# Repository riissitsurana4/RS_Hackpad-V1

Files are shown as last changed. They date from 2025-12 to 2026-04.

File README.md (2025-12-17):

  # RS_Hackpad-V1

Hello everyone!
This is my first hardware project, built as part of **Blueprint (Hack Club)**.

It is a custom macropad made using switches, a rotatory encoder, oled display, etc.

---

## Case Design

The case consists of **two 3D-printed parts**

* **Top plate**
* **Base case**

Bottom case design

Top plate design

---

## PCB Design

The PCB was designed in **KiCad** and includes the following features:

* **8 mechanical switches** arranged in a matrix (4 columns × 2 rows)
* **8 SK6812 RGB LEDs** for underglow
* **1 rotary encoder**
* **0.91 inch OLED display**
* **Seeed XIAO RP2040** as the MCU

The LEDs are placed near the edges of the PCB to create an underglow effect through the case.

PCB layout

---
## Final Design
Arranged 3D version of all the parts including the pcb.

Final PCB render

---

## Firmware

I have made the firmware using **KMK**. 

I have only made basic firmware as it is very confusing and i do not have anything to test on.

---

## BOM

Seeed XIAO RP2040 

Through-hole 1N4148 Diodes (x9)

MX-Style switches (x8)

EC11 Rotary encoders (x1)

0.91 inch OLED displays

SK6812 MINI-E LEDs (x8)

M3x16mm screws & M3x5mx4mm heatset inserts

---

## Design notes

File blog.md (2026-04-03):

This was my first hardware project which taught me multiple things.... Used KiCad and Fusion for the first time.

I recievd all the parts for my hackpad, but later found out that i did not upload all the files needed for the pcb.
I had not uploaded the drill filles and hence the pcb was without holes needed.
My case does not has any tolerance and is a little small (2mm) than the pcb...

As the pcb is incorect and the case is a little small, was not able to complete this project.... Will definitely make a V2 of this and fix most of my mistakes.

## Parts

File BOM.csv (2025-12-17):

Part Name | Quantity | LINK
SeeedXIAO RP2040 | 1 | HACKPAD KIT
Through-hole 1N4148 Diodes | 9 | HACKPAD KIT
MX-Style switches | 8 | HACKPAD KIT
EC11 Rotary encoders | 1 | HACKPAD KIT
0.91 inch OLED displays | 1 | HACKPAD KIT
SK6812 MINI-E LEDs | 8 | HACKPAD KIT
M3x16mm screws & M3x5mx4mm heatset inserts | 4 | HACKPAD KIT
PCB | 1 | JLPCB
Soldering Iron | 1

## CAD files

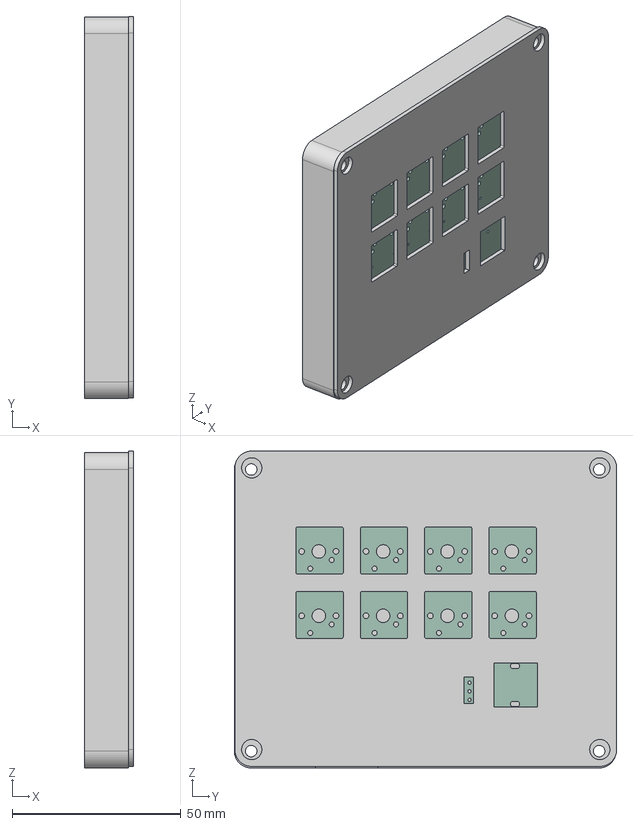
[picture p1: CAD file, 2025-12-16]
CAD/macropad_RS_fullcase.step
14.5 x 113.2 x 93.9 mm

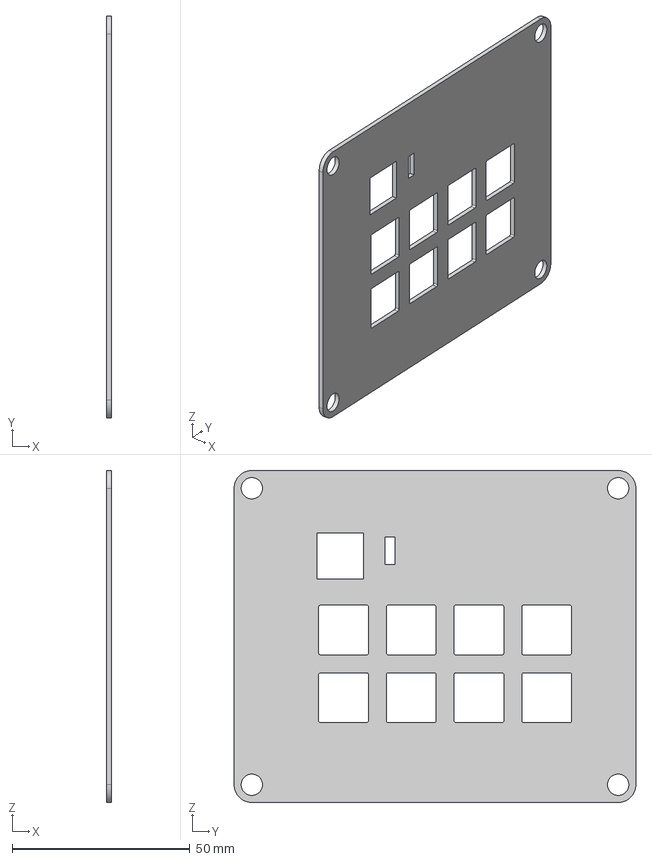
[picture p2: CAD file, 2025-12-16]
CAD/RS_macropad_top.step
1.50 x 113.1 x 93.4 mm

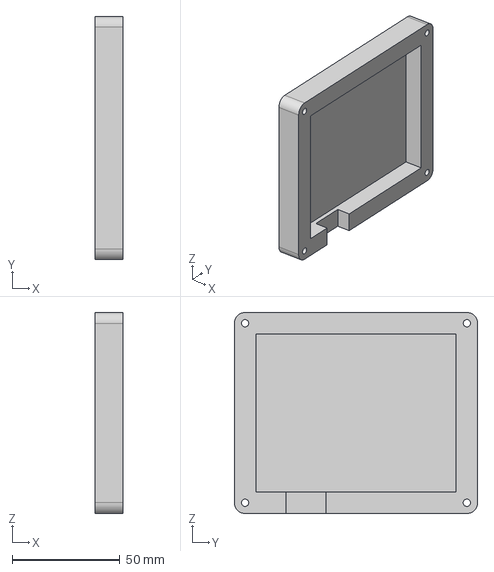
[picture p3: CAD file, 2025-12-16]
CAD/RS Macropad_base.step
13.0 x 113.1 x 93.4 mm

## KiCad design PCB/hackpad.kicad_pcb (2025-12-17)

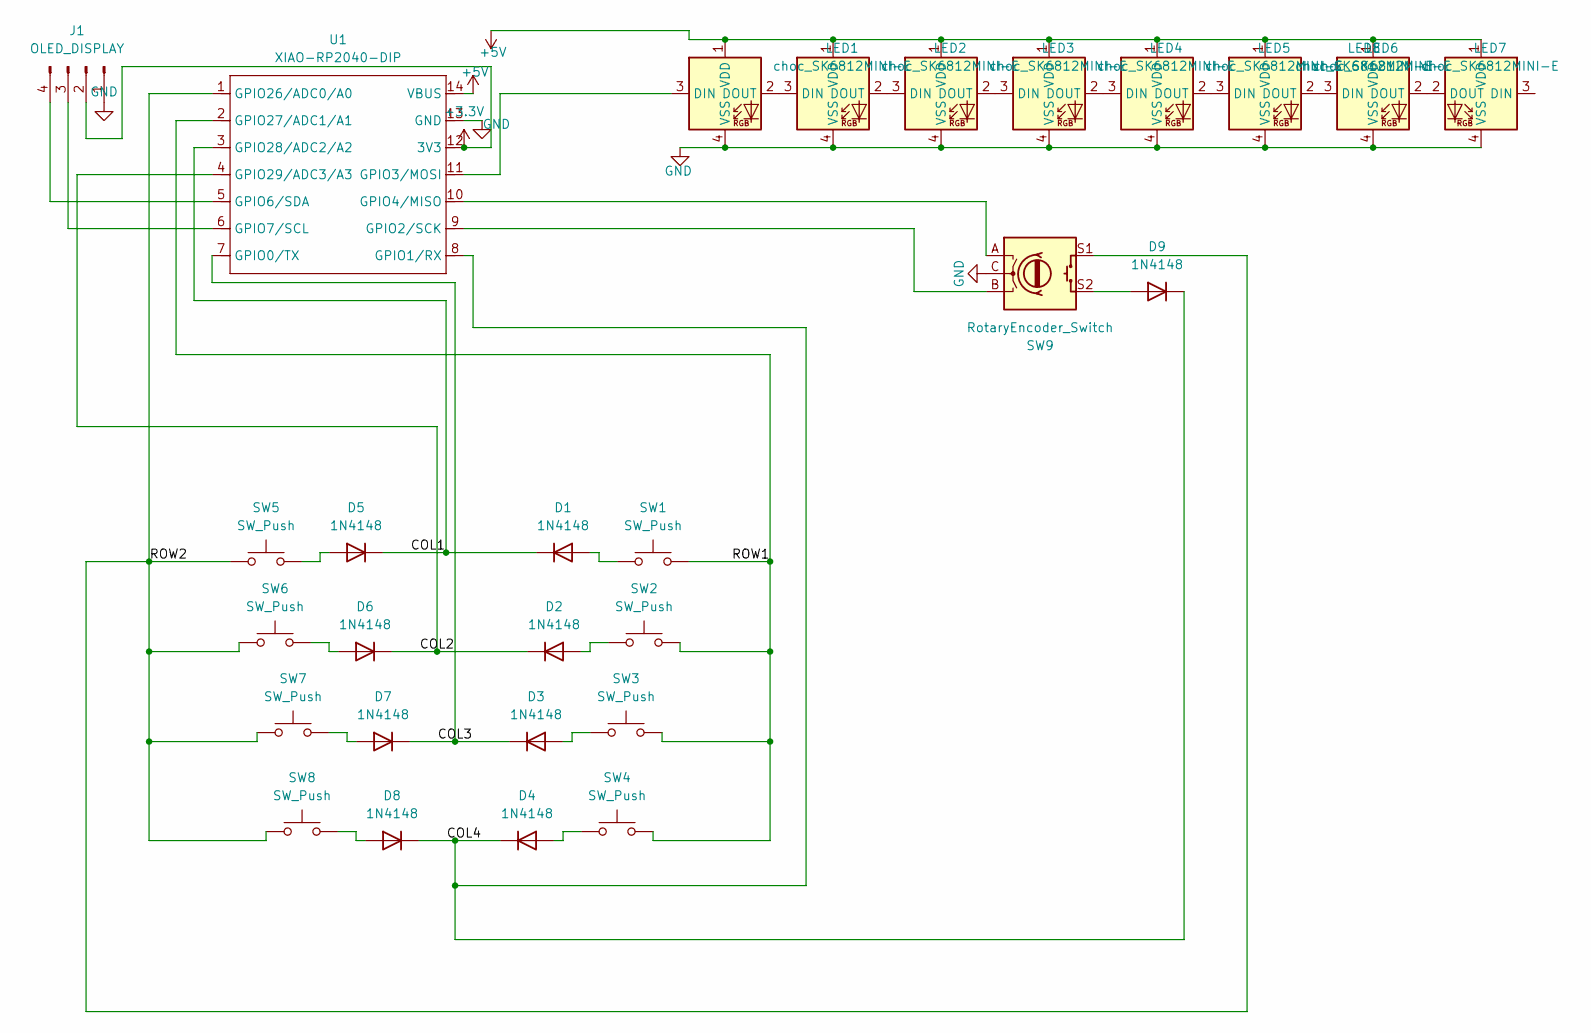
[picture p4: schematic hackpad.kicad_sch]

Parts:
D1, D2, D3, D4, D5, D6, D7, D8, D9: 1N4148; D_DO-35_SOD27_P7.62mm_Horizontal
J1: OLED_DISPLAY; PinHeader_1x04_P2.54mm_Vertical
LED1, LED2, LED3, LED4, LED5, LED6, LED7, LED8: choc_SK6812MINI-E; LED_SK6812MINI_PLCC4_3.5x3.5mm_P1.75mm
SW1, SW2, SW3, SW4, SW5, SW6, SW7, SW8: SW_Push; SW_Cherry_MX_1.00u_PCB
SW9: RotaryEncoder_Switch; RotaryEncoder_Alps_EC11E-Switch_Vertical_H20mm
U1: XIAO-RP2040-DIP

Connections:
+3.3V: J1.2, U1.12 (3V3)
+5V: LED1.1 (VDD), LED2.1 (VDD), LED3.1 (VDD), LED4.1 (VDD), LED5.1 (VDD), LED6.1 (VDD), LED7.1 (VDD), LED8.1 (VDD), U1.14 (VBUS)
/COL1: D1.1 (K), D5.1 (K), U1.3 (GPIO28/ADC2/A2)
/COL2: D2.1 (K), D6.1 (K), U1.4 (GPIO29/ADC3/A3)
/COL3: D3.1 (K), D7.1 (K), U1.7 (GPIO0/TX)
/COL4: D4.1 (K), D8.1 (K), D9.1 (K), U1.8 (GPIO1/RX)
/ROW1: SW1.1, SW2.1, SW3.1, SW4.1, U1.2 (GPIO27/ADC1/A1)
/ROW2: SW5.1, SW6.1, SW7.1, SW8.1, SW9.S1, U1.1 (GPIO26/ADC0/A0)
GND: J1.1, LED1.4 (VSS), LED2.4 (VSS), LED3.4 (VSS), LED4.4 (VSS), LED5.4 (VSS), LED6.4 (VSS), LED7.4 (VSS), LED8.4 (VSS), SW9.C, U1.13 (GND)
unnamed: D1.2 (A), SW1.2
unnamed: D2.2 (A), SW2.2
unnamed: D3.2 (A), SW3.2
unnamed: D4.2 (A), SW4.2
unnamed: D5.2 (A), SW5.2
unnamed: D6.2 (A), SW6.2
unnamed: D7.2 (A), SW7.2
unnamed: D8.2 (A), SW8.2
unnamed: D9.2 (A), SW9.S2
unnamed: J1.3, U1.6 (GPIO7/SCL)
unnamed: J1.4, U1.5 (GPIO6/SDA)
unnamed: LED1.3 (DIN), U1.11 (GPIO3/MOSI)
unnamed: LED1.2 (DOUT), LED2.3 (DIN)
unnamed: LED2.2 (DOUT), LED3.3 (DIN)
unnamed: LED3.2 (DOUT), LED4.3 (DIN)
unnamed: LED4.2 (DOUT), LED5.3 (DIN)
unnamed: LED5.2 (DOUT), LED6.3 (DIN)
unnamed: LED6.2 (DOUT), LED7.3 (DIN)
unnamed: LED7.2 (DOUT), LED8.2 (DOUT)
unnamed: SW9.B, U1.9 (GPIO2/SCK)
unnamed: SW9.A, U1.10 (GPIO4/MISO)

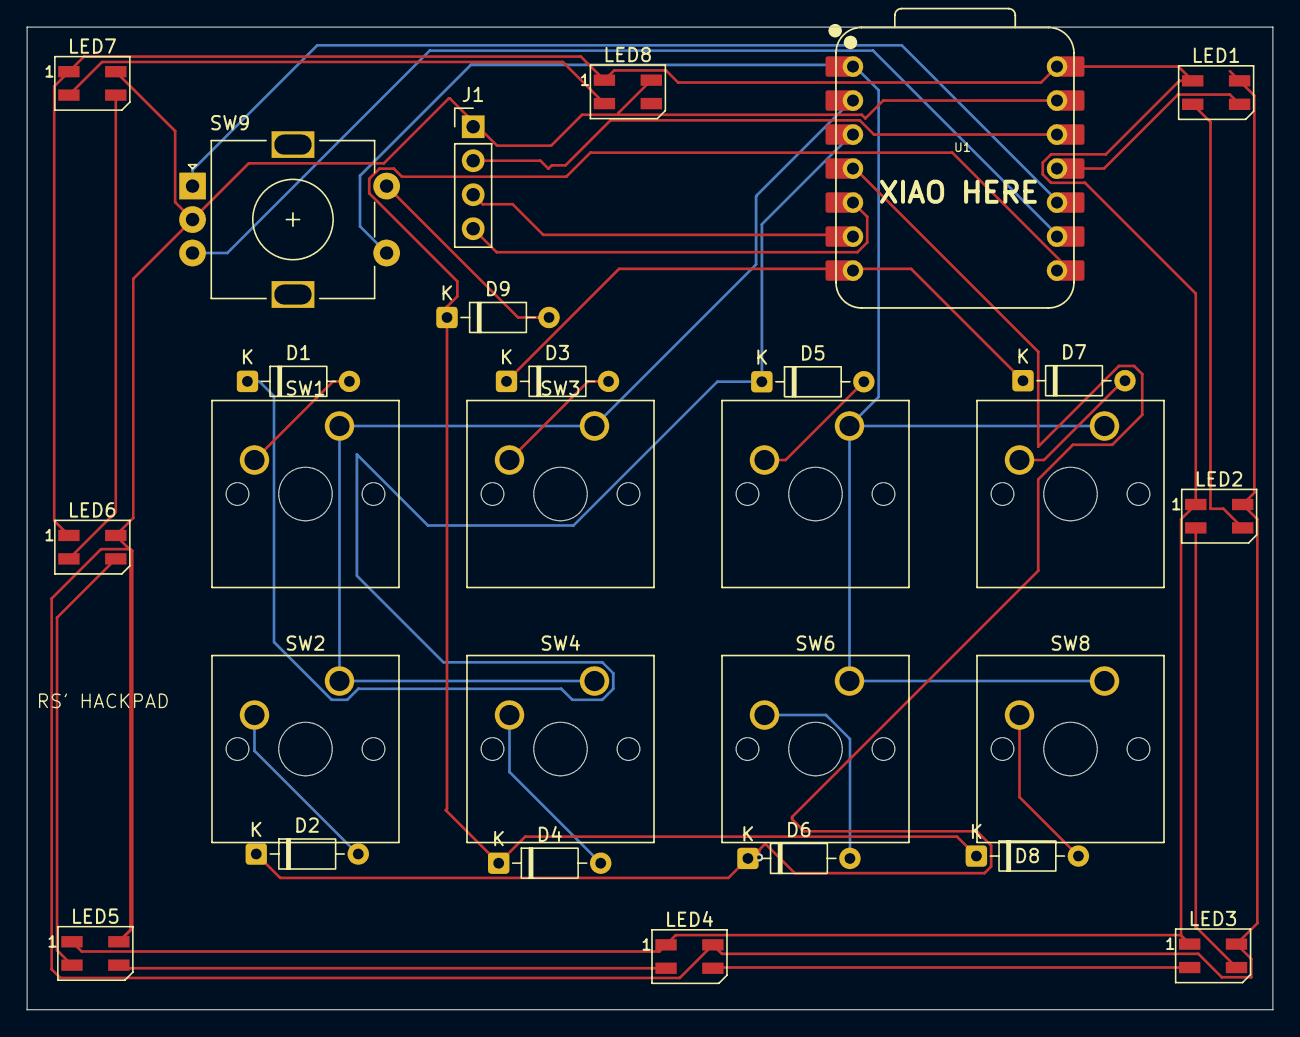
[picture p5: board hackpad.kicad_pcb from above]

Board: 2 copper layers, 93.1 x 73.4 mm, 28 parts (0 on the bottom side), 30 nets.

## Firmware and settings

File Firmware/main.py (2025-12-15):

import board
from kmk.kmk_keyboard import KMKKeyboard
from kmk.keys import KC
from kmk.scanners import DiodeOrientation

keyboard = KMKKeyboard()

keyboard.col_pins = (
    board.GPIO28,  # COL1
    board.GPIO29,  # COL2
    board.GPIO0,  # COL3
    board.GPIO1,  # COL4
)

keyboard.row_pins = (
    board.GPIO26,  # ROW1
    board.GPIO27,  # ROW2
)

keyboard.diode_orientation = DiodeOrientation.COL2ROW


keyboard.keymap = [
    [
        KC.Q, KC.W, KC.E, KC.R,
        KC.A, KC.S, KC.D, KC.F,
    ]
]


if __name__ == "__main__":
    keyboard.go()

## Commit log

2025-12-15 uploading necessary files
    [RS Macropad_full.step, hackpad.kicad_pcb, hackpad.kicad_sch]
2025-12-16 uploading stuff
    [RS Macropad_base.step, RS Macropad_full.step, RS_macropad_top.step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]
2025-12-16 Updated Readme
    Expanded the README to include detailed project information, including case design, PCB design, final design, and firmware details.
2025-12-17 adding BOM
2025-12-17 uploading files
    clearing drc
    [hackpad.kicad_pcb, hackpad.step]
2026-03-23 adding blog.md
    Added a note about missing drill files for the PCB.
